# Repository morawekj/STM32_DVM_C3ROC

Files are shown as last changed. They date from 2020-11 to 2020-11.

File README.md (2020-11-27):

# STM32_DVM_C3ROC

This is a fork of the STM32 DVM V4 from Scott Zimmerman N3XCC / Repeater Builder
Inspired from a similar design: github.com/wojciechk8/MMDVM_pog
Low-pass filter design by SQ6POG

I design a new KiCad Design with some improvements and separate LED Board with I2C and RS232 Display connections. Also with an 5V 3.5A DC/DC converter with TI TPS54360(B) for the Raspberry PI, so that can powered from the radios DC voltage. Also add some ferrite beads and USBCL6 TVS protection. Connection to the LED/Display is a 20 Pin ribbon cable.

This project is mainly design for use for use on Chaos Computer Clubs Radio Teams (c3roc) DMR repeaters. All credits go to first designers. May be some others HAMs find this useful and feel free to use.

PCB and Components can be easy source by some prototype manufactures.

Enjoy RFguy DG3FDM

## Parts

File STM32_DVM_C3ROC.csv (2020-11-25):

ID | Designator | Footprint | Stückzahl | Comment | MFR.Part # | LCSC Part #
1 | R6,R51,R23 | Potentiometer_Bourns_3296W_Vertical | 3 | 100k | DNP
2 | X2 | DSUB-9_Female_Horizontal_P2.77x2.84mm_EdgePinOffset4.94mm_Housed_MountingHolesOffset7.48mm | 1 | To Radio | DNP
3 | SW1 | SW_Push_SPST_NO_Alps_SKRK | 1 | SW_Push | TS-1187A-C-C-B | C318889 | ext | 0,0348 $
4 | R32 | Potentiometer_Bourns_3296W_Vertical | 1 | 10k | DNP
5 | X1 | SMD-7050_4P | 1 | ASE-12MHz | O705012MHEA4SI | C70647 | ext | 0,4957 $
6 | U5 | TI_SO-PowerPAD-8_ThermalVias | 1 | TPS54360DDA | TPS54360DDAR | C44377 | ext | 0,9958 $
7 | U4,U3,U2 | SOT-23-6 | 3 | USBLC6-2SC6 | USBLC6-2SC6 | C7519 | ext | 0,0874 $
8 | U1 | LQFP-64_10x10mm_P0.5mm | 1 | STM32F446RETx | STM32F446RET6 | C69336 | ext | 3,5218 $
9 | TP7 | TestPoint_Pad_1.5x1.5mm | 1 | RSSI | DNP
10 | TP6 | TestPoint_Pad_1.5x1.5mm | 1 | TXA_R | DNP
11 | TP5,TP2,TP1 | TestPoint_Pad_1.5x1.5mm | 3 | TestPoint | DNP
12 | TP3 | TestPoint_Pad_1.5x1.5mm | 1 | RXA | DNP
13 | T4,T3,T2,T1 | SOT-23 | 4 | MMUN2214 | MMUN2214LT1G | C82089 | ext
14 | SJ1 | SolderJumper-2_P1.3mm_Open_Pad1.0x1.5mm | 1 | Jumper_2_Open | DNP
15 | R56,R50,R49,R48,R47,R46,R45,R44,R43,R42,R37 | R_0603_1608Metric | 11 | 560R | 0603WAF5600T5E | C23204 | basic | 0,0018 $
16 | R55,R53 | R_0603_1608Metric | 2 | 10k2 | 0603WAF1022T5E | C22772 | ext | 0,0024 $
17 | R54 | R_0603_1608Metric | 1 | 53k6 | 0603WAF5362T5E | C23074 | ext | 0,0026 $
18 | R52 | R_0603_1608Metric | 1 | 162k | 0603WAF1623T5E | C22815 | ext | 0,0026 $
19 | R41,R36,R34,R2,R1 | R_0603_1608Metric | 5 | 1k | 0603WAF1001T5E | C21190 | basic | 0,0021 $
20 | R35,R33,R19,R18,R8,R5,R17,R10,R4,R3 | R_0603_1608Metric | 10 | 10k | 0603WAF1002T5E | C25804 | basic | 0,0019 $
21 | R39 | R_0603_1608Metric | 1 | 4k7 | 0603WAF4701T5E | C23162 | basic | 0,0016 $
22 | R38,R30 | R_0603_1608Metric | 2 | 47k | 0603WAF4702T5E | C25819 | basic | 0,0018 $
23 | R31,R29,R9 | R_0603_1608Metric | 3 | 47R | 0603WAF470JT5E | C23182 | basic | 0,0024 $
24 | R28,R26 | R_0603_1608Metric | 2 | 3k9 | 0603WAF3901T5E | C23018 | basic | 0,0021 $
25 | R27,R24 | R_0603_1608Metric | 2 | 39k | 0603WAF3902T5E | C23153 | basic | 0,0019 $
26 | R25,R22 | R_0603_1608Metric | 2 | 3k3 | 0603WAF3301T5E | C22978 | basic | 0,0021 $
27 | R21,R16,R15 | R_0603_1608Metric | 3 | 100k | 0603WAF1003T5E | C25803 | basic | 0,0018 $
28 | R20 | R_0603_1608Metric | 1 | 68k | 0603WAF6802T5E | C23231 | basic | 0,0019 $
29 | R18 | R_0603_1608Metric | 4 | 523k | 0603WAF5233T5E | C23076 | ext | 0,0026 $
 | R40 | R_0603_1608Metric | 1 | 82k | 0603WAF8202T5E | C23254 | basic | 0,0021 $
30 | R14,R13,R12,R11 | R_0603_1608Metric | 4 | 22k | 0603WAF2202T5E | C31850 | basic | 0,0019 $
31 | R7 | R_0603_1608Metric | 1 | 100R | 0603WAF1000T5E | C22775 | basic | 0,0019 $
32 | Q1 | Crystal_SMD_3225-4Pin_3.2x2.5mm | 1 | Crystal_GND23 | 1C208000BC0R | C57131 | ext | 0,341 $
33 | LED12 | LED_0603_1608Metric | 1 | white |  | C2290 | basic | 0,0133 $
34 | LED11,LED10,LED9,LED8,LED7 | LED_0603_1608Metric | 5 | YEL | 19-213/Y2C-CQ2R2L/3T(CY) | C72038 | basic | 0,0233 $
35 | LED6,LED1 | LED_0603_1608Metric | 2 | RED | KT-0603R | C2286 | basic | 0,0079 $
36 | LED5 | LED_0603_1608Metric | 1 | GRN | 19-217/GHC-YR1S2/3T | C72043 | basic | 0,0375 $
37 | LED4,LED3 | LED_0603_1608Metric | 2 | ORG | E6C0603SEAC1UDA | C375450 | ext | 0,585 $
38 | LED2 | LED_0603_1608Metric | 1 | BLU | 19-217/BHC-ZL1M2RY/3T | C72041 | basic | 0,0242 $
39 | L1 | L_Coilcraft_XAL60xx_6.36x6.56mm | 1 | 8u2 | APS07A30M8R2 | C328254 | ext | 0,1502 $
40 | JP5 | PinHeader_2x10_P2.54mm_Vertical | 1 | To STM32 DVM | DNP
41 | JP4 | PinHeader_2x10_P2.54mm_Vertical | 1 | To LED + Display | DNP
42 | JP3 | PinHeader_2x03_P2.54mm_Vertical | 1 | Debug | DNP
43 | JP2 | PinHeader_1x04_P2.54mm_Vertical | 1 | Nextion Display | DNP
44 | JP1 | PinHeader_1x04_P2.54mm_Vertical | 1 | I2C Display | DNP
45 | J2 | USB_Micro-B_Molex_47346-0001 | 1 | USB_B_Micro | DNP
46 | IC4,IC3,IC2 | SO-8_3.9x4.9mm_P1.27mm | 3 | MCP6002 | MCP6002-I/SN | C116706 | ext | 0,2117 $
47 | FB23,FB22,FB21,FB20,FB19,FB18,FB17,FB16,FB15,FB14,FB13,FB12,FB11,FB10,FB9,FB8,FB7,FB6,FB5,FB4,FB3,FB2,FB1 | L_0603_1608Metric | 23 | 100 | GZ1608D601TF | C1002 | ext | 0,0068 $
48 | D2 | D_SMC | 1 | B560C | B560C-13-F | C85100 | ext | 0,1531 $
49 | D1 | SOT-23 | 1 | BAV70 | BAV70 | C68978 | basic | 0,027 $
50 | C43,C41 | C_1206_3216Metric | 2 | 1u | CL31B105KBHNNNE | C1848 | basic | 0,0324 $
51 | C42,C30,C27,C26,C24 | C_0603_1608Metric | 5 | 10n | 0603B103K500NT | C57112 | basic | 0,0055 $
52 | C38,C16,C10,C7,C6,C5,C3,C2,C1 | C_0603_1608Metric | 9 | 100n | CC0603KRX7R9BB104 | C14663 | basic | 0,0063 $
54 | C37 | C_0603_1608Metric | 1 | 47p | CL10C470JB8NNNC | C1671 | basic | 0,0072 $
55 | C36 | C_0603_1608Metric | 1 | 6n8 | 0603B682K500NT | C1631 | basic | 0,0021 $
56 | C35,C4,C32,C28,C18,C11,C9,C8 | C_1206_3216Metric | 8 | 4u7 | 1206B475K500NT | C29823 | basic | 0,0635 $
57 | C40,C39,C34,C33,C20,C19,C14 | C_1210_3225Metric | 7 | 22u | TMK325BJ226KM-P | C268020 | ext | 0,1356 $
58 | C31,C29 | C_0603_1608Metric | 2 | 680p | 0603B681K500NT | C1630 | basic | 0,0059 $
59 | C25,C23 | C_1206_3216Metric | 2 | 2u2 | CL31B225KBHNNNE | C50254 | basic | 0,0525 $
60 | C22,C21,C17,C15 | C_1210_3225Metric | 4 | 47u | GRM32ER61C476KE15L | C77101 | ext | 0,1884 $
61 | C13,C12 | C_0603_1608Metric | 2 | 10p | CL10C100JB8NNNC | C1634 | basic | 0,0083 $
62 | J1 | PinSocket_2x20_P2.54mm_Vertical | 1 | 40HAT | DNP
63 | H1,H2,H3,H4 | NPTH_3mm_ID | 4 | 3mm | DNP
64

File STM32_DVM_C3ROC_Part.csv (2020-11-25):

Designator | Footprint | Comment | LCSC | Part | #
R6,R51,R23 | Potentiometer_Bourns_3296W_Vertical | 100k
X2 | DSUB-9_Female_Horizontal_P2.77x2.84mm_EdgePinOffset4.94mm_Housed_MountingHolesOffset7.48mm | To | Radio
SW1 | SW_Push_SPST_NO_Alps_SKRK | SW_Push | C318889
R32 | Potentiometer_Bourns_3296W_Vertical | 10k
X1 | SMD-7050_4P | ASE-12MHz | C70647
U5 | TI_SO-PowerPAD-8_ThermalVias | TPS54360DDA | C44377
U4,U3,U2 | SOT-23-6 | USBLC6-2SC6 | C111212
U1 | LQFP-64_10x10mm_P0.5mm | STM32F446RETx | C69336
TP7 | TestPoint_Pad_1.5x1.5mm | RSSI
TP6 | TestPoint_Pad_1.5x1.5mm | TXA_R
TP5,TP2,TP1 | TestPoint_Pad_1.5x1.5mm | TestPoint
TP3 | TestPoint_Pad_1.5x1.5mm | RXA
T4,T3,T2,T1 | SOT-23 | MMUN2214 | C82089
SJ1 | SolderJumper-2_P1.3mm_Open_Pad1.0x1.5mm | Jumper_2_Open
R56,R50,R49,R48,R47,R46,R45,R44,R43,R42,R37 | R_0603_1608Metric | 560R | C23204
R55,R53 | R_0603_1608Metric | 10k2 | C22772
R54 | R_0603_1608Metric | 53k6 | C23074
R52 | R_0603_1608Metric | 162k | C22815
R41,R36,R34,R2,R1 | R_0603_1608Metric | 1k | C21190
R35,R33,R19,R8,R5,R17,R10,R4,R3 | R_0603_1608Metric | 10k | C25804
R39 | R_0603_1608Metric | 4k7 | C23162
R38,R30 | R_0603_1608Metric | 47k | C25819
R31,R29,R9 | R_0603_1608Metric | 47R | C23182
R28,R26 | R_0603_1608Metric | 3k9 | C23018
R27,R24 | R_0603_1608Metric | 39k | C23153
R25,R22 | R_0603_1608Metric | 3k3 | C22978
R21,R16,R15 | R_0603_1608Metric | 100k | C25803
R20 | R_0603_1608Metric | 68k | C23231
R18 | R_0603_1608Metric | 523k | C23076
R40 | R_0603_1608Metric | 82k | C23254
R14,R13,R12,R11 | R_0603_1608Metric | 22k | C31850
R7 | R_0603_1608Metric | 100R | C22775
Q1 | Crystal_SMD_3225-4Pin_3.2x2.5mm | Crystal_GND23 | C57131
LED12 | LED_0603_1608Metric | white | C2290
LED11,LED10,LED9,LED8,LED7 | LED_0603_1608Metric | YEL | C72038
LED6,LED1 | LED_0603_1608Metric | RED | C2286
LED5 | LED_0603_1608Metric | GRN | C72043
LED4,LED3 | LED_0603_1608Metric | ORG | C375450
LED2 | LED_0603_1608Metric | BLU | C72041
L1 | L_Coilcraft_XAL60xx_6.36x6.56mm | 8u2 | C328254
JP5 | PinHeader_2x10_P2.54mm_Vertical | To | STM32 | DVM
JP4 | PinHeader_2x10_P2.54mm_Vertical | To | LED | + | Display
JP3 | PinHeader_2x03_P2.54mm_Vertical | Debug
JP2 | PinHeader_1x04_P2.54mm_Vertical | Nextion | Display
JP1 | PinHeader_1x04_P2.54mm_Vertical | I2C | Display
J2 | USB_Micro-B_Molex_47346-0001 | USB_B_Micro
IC4,IC3,IC2 | SO-8_3.9x4.9mm_P1.27mm | MCP6002 | C116706
FB23,FB22,FB21,FB20,FB19,FB18,FB17,FB16,FB15,FB14,FB13,FB12,FB11,FB10,FB9,FB8,FB7,FB6,FB5,FB4,FB3,FB2,FB1 | L_0603_1608Metric | 100n | C1002
D2 | D_SMC | B560C | C85100
D1 | SOT-23 | BAV70 | C68978
C43,C41 | C_1206_3216Metric | 1u | C1848
C42,C30,C27,C26,C24 | C_0603_1608Metric | 10n | C57112
C38,C16,C10,C7,C6,C5,C3,C2,C1 | C_0603_1608Metric | 100n | C14663
C37 | C_0603_1608Metric | 47p | C1671
C36 | C_0603_1608Metric | 6n8 | C1631
C35,C4,C32,C28,C18,C11,C9,C8 | C_1206_3216Metric | 4u7 | C29823
C40,C39,C34,C33,C20,C19,C14 | C_1210_3225Metric | 22u | C268020
C31,C29 | C_0603_1608Metric | 680p | C1630
C25,C23 | C_1206_3216Metric | 2u2 | C50254
C22,C21,C17,C15 | C_1210_3225Metric | 47u | C77101
C13,C12 | C_0603_1608Metric | 10p | C1634
J1 | PinSocket_2x20_P2.54mm_Vertical | 40HAT
H1,H2,H3,H4 | NPTH_3mm_ID | 3mm

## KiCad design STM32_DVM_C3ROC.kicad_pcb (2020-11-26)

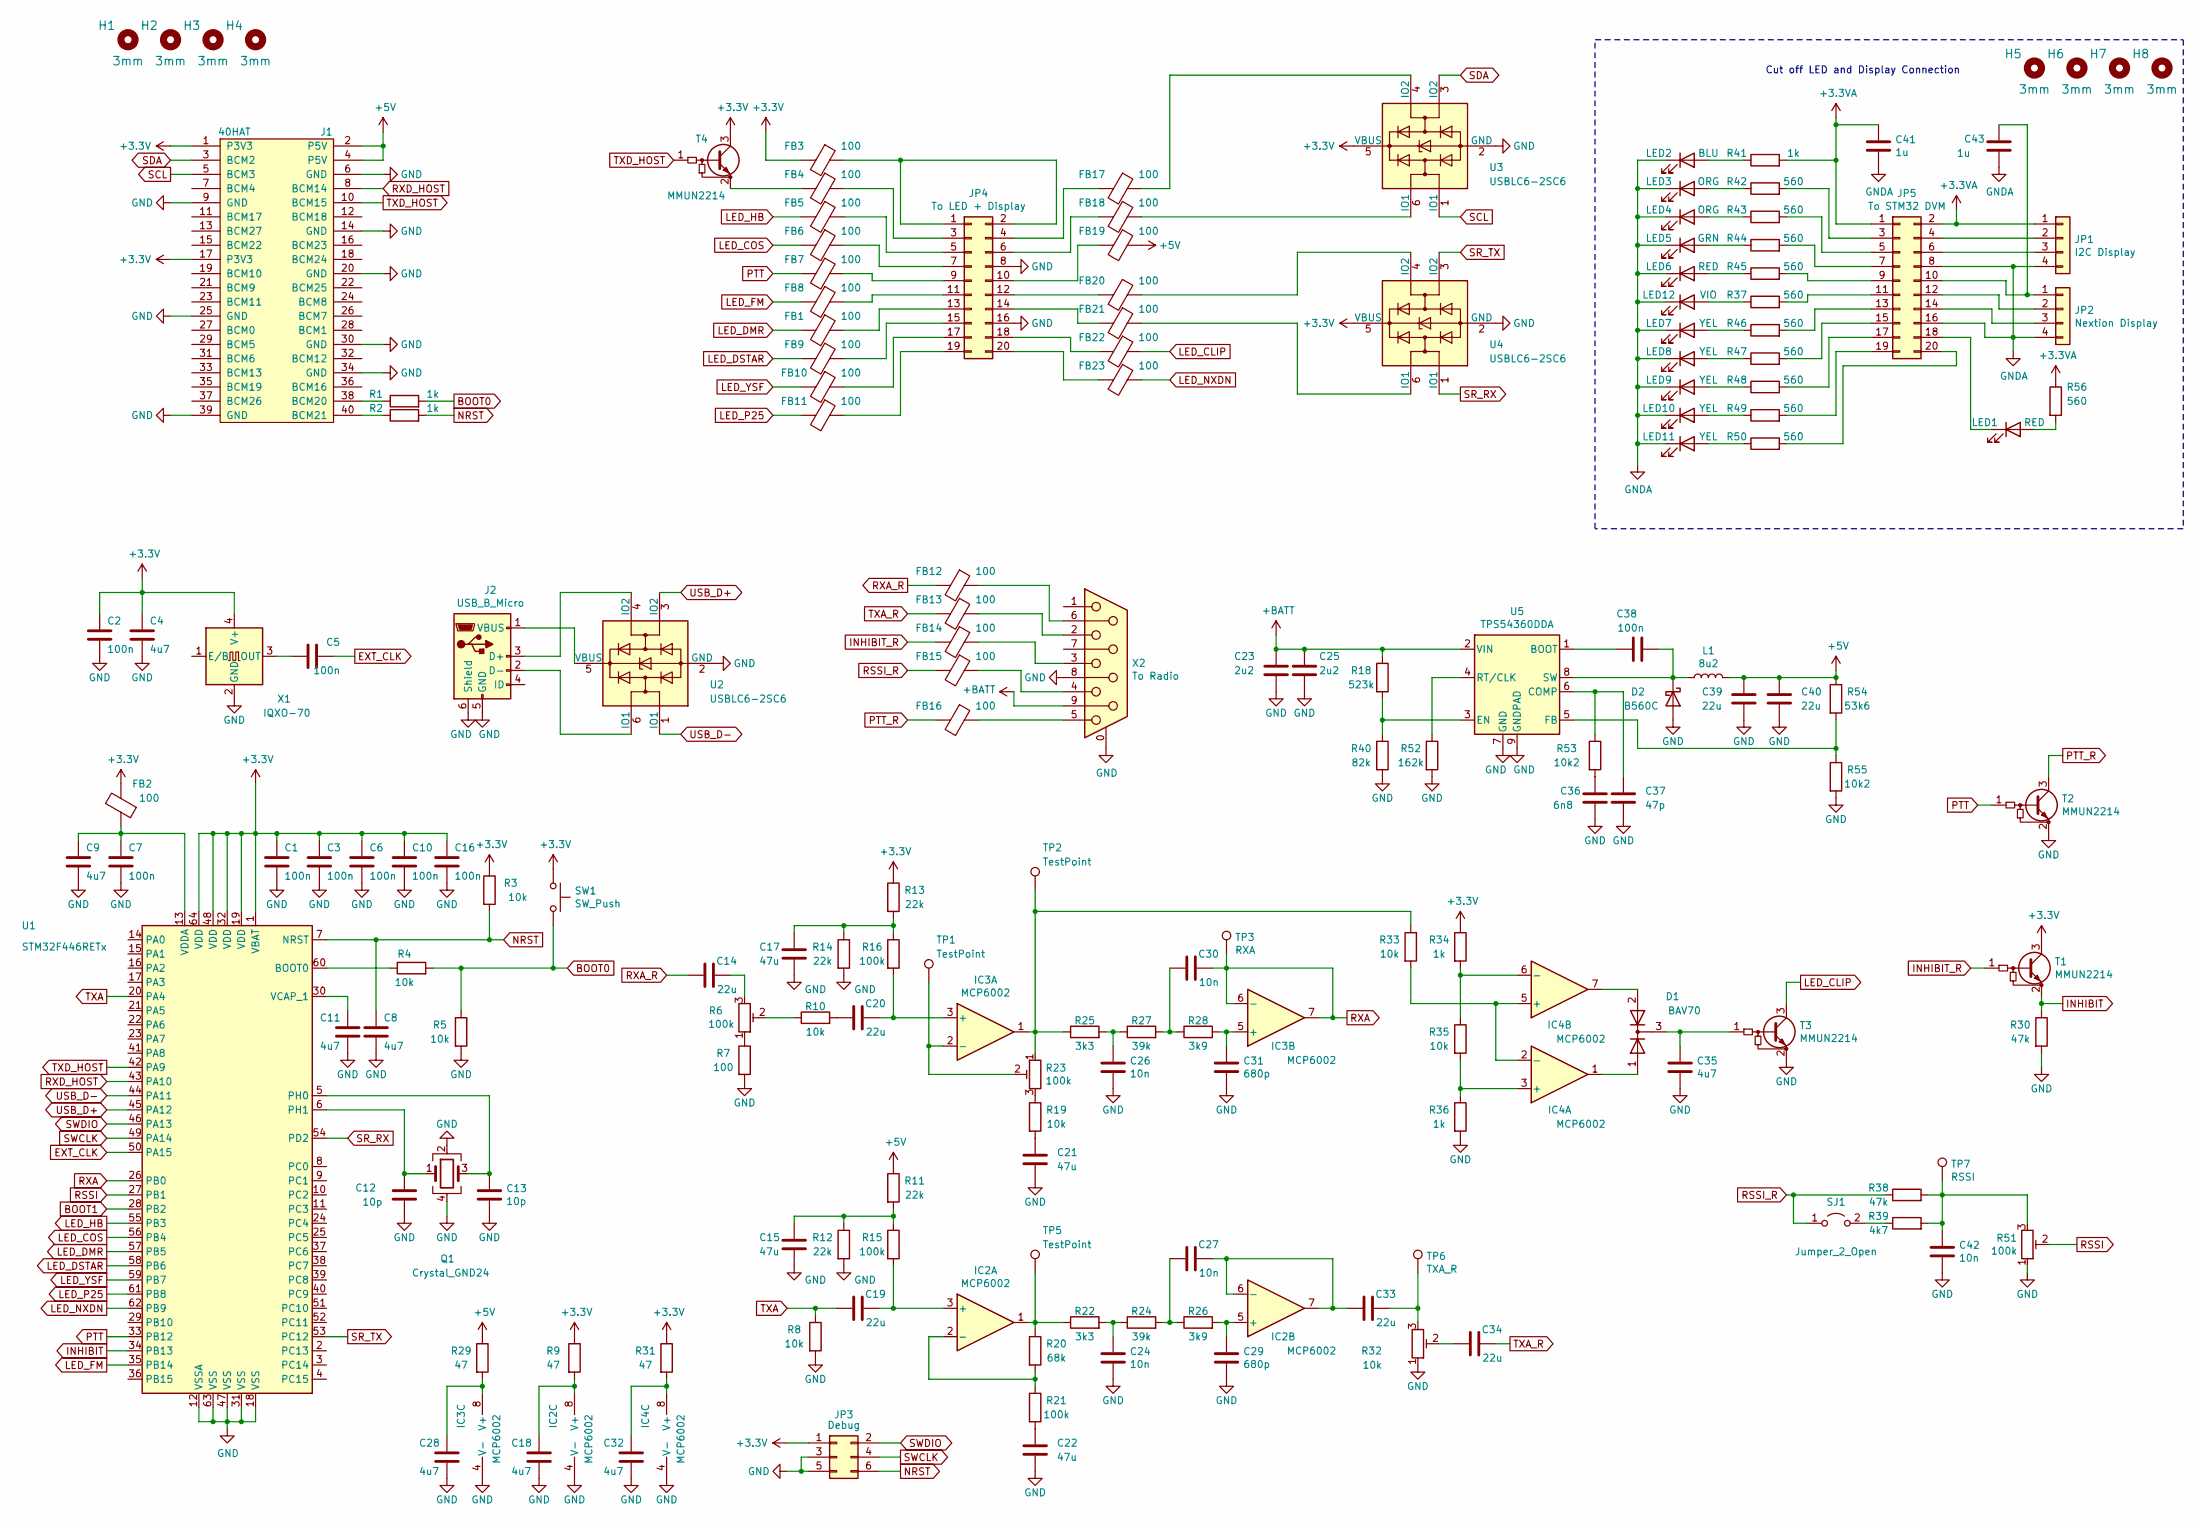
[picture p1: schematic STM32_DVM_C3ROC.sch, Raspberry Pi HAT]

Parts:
C1, C2, C3, C5, C6, C7, C10, C16, C38: 100n; C_0603_1608Metric
C4, C8, C9, C11, C18, C28, C32, C35: 4u7; C_1206_3216Metric
C12, C13: 10p; C_0603_1608Metric
C14, C19, C20, C33, C34, C39, C40: 22u; C_1210_3225Metric
C15, C17, C21, C22: 47u; C_1210_3225Metric
C23, C25: 2u2; C_1206_3216Metric
C24, C26, C27, C30, C42: 10n; C_0603_1608Metric
C29, C31: 680p; C_0603_1608Metric
C36: 6n8; C_0603_1608Metric
C37: 47p; C_0603_1608Metric
C41, C43: 1u; C_1206_3216Metric
D1: BAV70; SOT-23
D2: B560C; D_SMC
FB1, FB2, FB3, FB4, FB5, FB6, FB7, FB8, FB9, FB10, FB11, FB12, FB13, FB14, FB15, FB16, FB17, FB18, FB19, FB20, FB21, FB22, FB23: 100; L_0603_1608Metric
H1, H2, H3, H4, H5, H6, H7, H8: 3mm; NPTH_3mm_ID
IC2, IC3, IC4: MCP6002; SO-8_3.9x4.9mm_P1.27mm
J1: 40HAT; PinSocket_2x20_P2.54mm_Vertical
J2: USB_B_Micro; USB_Micro-B_Molex_47346-0001
JP1: I2C Display; PinHeader_1x04_P2.54mm_Vertical
JP2: Nextion Display; PinHeader_1x04_P2.54mm_Vertical
JP3: Debug; PinHeader_2x03_P2.54mm_Vertical
JP4: To LED + Display; PinHeader_2x10_P2.54mm_Vertical
JP5: To STM32 DVM; PinHeader_2x10_P2.54mm_Vertical
L1: 8u2; L_Bourns_SRP7028A_7.3x6.6mm
LED1, LED6: RED; LED_0603_1608Metric
LED2: BLU; LED_0603_1608Metric
LED3, LED4: ORG; LED_0603_1608Metric
LED5: GRN; LED_0603_1608Metric
LED7, LED8, LED9, LED10, LED11: YEL; LED_0603_1608Metric
LED12: VIO; LED_0603_1608Metric
Q1: Crystal_GND24; Crystal_SMD_3225-4Pin_3.2x2.5mm
R1, R2, R34, R36, R41: 1k; R_0603_1608Metric
R3, R4, R5, R8, R10, R19, R33, R35: 10k; R_0603_1608Metric
R6, R23, R51: 100k; Potentiometer_Bourns_3296W_Vertical
R7: 100; R_0603_1608Metric
R9, R29, R31: 47; R_0603_1608Metric
R11, R12, R13, R14: 22k; R_0603_1608Metric
R15, R16, R21: 100k; R_0603_1608Metric
R18: 523k; R_0603_1608Metric
R20: 68k; R_0603_1608Metric
R22, R25: 3k3; R_0603_1608Metric
R24, R27: 39k; R_0603_1608Metric
R26, R28: 3k9; R_0603_1608Metric
R30, R38: 47k; R_0603_1608Metric
R32: 10k; Potentiometer_Bourns_3296W_Vertical
R37, R42, R43, R44, R45, R46, R47, R48, R49, R50, R56: 560; R_0603_1608Metric
R39: 4k7; R_0603_1608Metric
R40: 82k; R_0603_1608Metric
R52: 162k; R_0603_1608Metric
R53, R55: 10k2; R_0603_1608Metric
R54: 53k6; R_0603_1608Metric
SJ1: Jumper_2_Open; SolderJumper-2_P1.3mm_Open_Pad1.0x1.5mm
SW1: SW_Push; SW_SPST_SKQG_WithoutStem
T1, T2, T3, T4: MMUN2214; SOT-23
TP1, TP2, TP5: TestPoint; TestPoint_Pad_D1.5mm
TP3: RXA; TestPoint_Pad_D1.5mm
TP6: TXA_R; TestPoint_Pad_D1.5mm
TP7: RSSI; TestPoint_Pad_D1.5mm
U1: STM32F446RETx; LQFP-64_10x10mm_P0.5mm
U2, U3, U4: USBLC6-2SC6; SOT-23-6
U5: TPS54360DDA; TI_SO-PowerPAD-8_ThermalVias
X1: IQXO-70; Oscillator_SMD_IQD_IQXO70-4Pin_7.5x5.0mm
X2: To Radio; DSUB-9_Female_Horizontal_P2.77x2.84mm_EdgePinOffset4.94mm_H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

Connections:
+3.3VA: C41.1, JP1.1, JP5.1, JP5.2, R41.2, R56.1
+3V3: C1.1, C2.1, C3.1, C4.1, C6.1, C10.1, C16.1, FB2.2, FB3.2, J1.1 (P3V3), J1.17 (P3V3), JP3.1, R3.1, R9.1, R13.1, R31.1, R34.1, SW1.1, T1.3 (C), T4.3 (C), U1.1 (VBAT), U1.19 (VDD), U1.32 (VDD), U1.48 (VDD), U1.64 (VDD), U3.5 (VBUS), U4.5 (VBUS), X1.4 (V+)
+5V: C39.1, C40.1, FB19.1, J1.2 (P5V), J1.4 (P5V), L1.2, R11.1, R29.1, R54.1
+BATT: C23.1, C25.1, R18.1, U5.2 (VIN), X2.9
BOOT0: R1.2, R4.2, R5.1, SW1.2
EXT_CLK: C5.2, U1.50 (PA15)
GND: C1.2, C2.2, C3.2, C4.2, C6.2, C7.2, C8.2, C9.2, C10.2, C11.2, C12.2, C13.2, C15.2, C16.2, C17.2, C18.2, C21.2, C22.2, C23.2, C24.2, C25.2, C26.2, C28.2, C29.2, C31.2, C32.2, C35.2, C36.2, C37.2, C39.2, C40.2, C42.2, D2.2 (A), IC2.4 (V-), IC3.4 (V-), IC4.4 (V-), J1.6 (GND), J1.9 (GND), J1.14 (GND), J1.20 (GND), J1.25 (GND), J1.30 (GND), J1.34 (GND), J1.39 (GND), J2.5 (GND), J2.6 (Shield), JP3.3, JP3.5, JP4.8, JP4.16, Q1.2, Q1.4, R5.2, R7.2, R8.2, R12.2, R14.2, R30.2, R32.1, R36.2, R40.2, R51.1, R52.2, R55.2, T2.2 (E), T3.2 (E), U1.12 (VSSA), U1.18 (VSS), U1.31 (VSS), U1.47 (VSS), U1.63 (VSS), U2.2 (GND), U3.2 (GND), U4.2 (GND), U5.7 (GND), U5.9 (GNDPAD), X1.2 (GND), X2.0 (PAD), X2.8
GNDA: C41.2, C43.2, JP1.4, JP2.4, JP5.8, JP5.16, LED2.1 (K), LED3.1 (K), LED4.1 (K), LED5.1 (K), LED6.1 (K), LED7.1 (K), LED8.1 (K), LED9.1 (K), LED10.1 (K), LED11.1 (K), LED12.1 (K)
INHIBIT: R30.1, T1.2 (E), U1.34 (PB13)
INHIBIT_R: FB14.2, T1.1 (B)
LED_CLIP: FB22.1, T3.3 (C)
LED_COS: FB6.2, U1.56 (PB4)
LED_DMR: FB1.2, U1.57 (PB5)
LED_DSTAR: FB9.2, U1.58 (PB6)
LED_FM: FB8.2, U1.35 (PB14)
LED_HB: FB5.2, U1.55 (PB3)
LED_NXDN: FB23.1, U1.62 (PB9)
LED_P25: FB11.2, U1.61 (PB8)
LED_YSF: FB10.2, U1.59 (PB7)
NRST: C8.1, JP3.6, R2.2, R3.2, U1.7 (NRST)
unnamed: C5.1, X1.3 (OUT)
unnamed: C7.1, C9.1, FB2.1, U1.13 (VDDA)
unnamed: C11.1, U1.30 (VCAP_1)
unnamed: C12.1, Q1.1, U1.6 (PH1)
unnamed: C13.1, Q1.3, U1.5 (PH0)
unnamed: C14.2, R6.3
unnamed: C15.1, R11.2, R12.1, R15.1
unnamed: C17.1, R13.2, R14.1, R16.1
unnamed: C18.1, IC2.8 (V+), R9.2
unnamed: C19.2, IC2.3 (+), R15.2
unnamed: C20.1, R10.2
unnamed: C20.2, IC3.3 (+), R16.2
unnamed: C21.1, R19.2
unnamed: C22.1, R21.2
unnamed: C24.1, R22.2, R24.1
unnamed: C26.1, R25.2, R27.1
unnamed: C27.1, R24.2, R26.1
unnamed: C27.2, C33.1, IC2.6 (-), IC2.7
unnamed: C28.1, IC3.8 (V+), R29.2
unnamed: C29.1, IC2.5 (+), R26.2
unnamed: C30.1, R27.2, R28.1
unnamed: C31.1, IC3.5 (+), R28.2
unnamed: C32.1, IC4.8 (V+), R31.2
unnamed: C33.2, R32.3, TP6.1
unnamed: C34.1, R32.2
unnamed: C35.1, D1.3 (K), T3.1 (B)
unnamed: C36.1, R53.2
unnamed: C37.1, R53.1, U5.6 (COMP)
unnamed: C38.1, U5.1 (BOOT)
unnamed: C38.2, D2.1 (K), L1.1, U5.8 (SW)
unnamed: C42.1, R38.2, R39.2, R51.3, TP7.1
unnamed: C43.1, JP2.1, JP5.10
unnamed: D1.1 (A), IC4.1
unnamed: D1.2 (A), IC4.7
unnamed: FB1.1, JP4.13
unnamed: FB3.1, JP4.1, JP4.2
unnamed: FB4.1, JP4.3
unnamed: FB4.2, T4.2 (E)
unnamed: FB5.1, JP4.5
unnamed: FB6.1, JP4.7
unnamed: FB7.1, JP4.9
unnamed: FB8.1, JP4.11
unnamed: FB9.1, JP4.15
unnamed: FB10.1, JP4.17
unnamed: FB11.1, JP4.19
unnamed: FB12.1, X2.6
unnamed: FB13.1, X2.2
unnamed: FB14.1, X2.3
unnamed: FB15.1, X2.4
unnamed: FB16.1, X2.5
unnamed: FB17.1, U3.4 (IO2)
unnamed: FB17.2, JP4.4
unnamed: FB18.1, U3.6 (IO1)
unnamed: FB18.2, JP4.6
unnamed: FB19.2, JP4.10
unnamed: FB20.1, U4.4 (IO2)
unnamed: FB20.2, JP4.12
unnamed: FB21.1, U4.6 (IO1)
unnamed: FB21.2, JP4.14
unnamed: FB22.2, JP4.18
unnamed: FB23.2, JP4.20
unnamed: IC2.1, R20.1, R22.1, TP5.1
unnamed: IC2.2 (-), R20.2, R21.1
unnamed: IC3.1, R23.1, R25.1, R33.1, TP2.1
unnamed: IC3.2 (-), R23.2, TP1.1
unnamed: IC4.2 (-), IC4.5 (+), R33.2
unnamed: IC4.3 (+), R35.2, R36.1
unnamed: IC4.6 (-), R34.2, R35.1
unnamed: J1.38 (BCM20), R1.1
unnamed: J1.40 (BCM21), R2.1
unnamed: J2.1 (VBUS), U2.5 (VBUS)
unnamed: J2.2 (D-), U2.6 (IO1)
unnamed: J2.3 (D+), U2.4 (IO2)
unnamed: JP1.2, JP5.4
unnamed: JP1.3, JP5.6
unnamed: JP2.2, JP5.12
unnamed: JP2.3, JP5.14
unnamed: JP5.3, R42.2
unnamed: JP5.5, R43.2
unnamed: JP5.7, R44.2
unnamed: JP5.9, R45.2
unnamed: JP5.11, R37.2
unnamed: JP5.13, R46.2
unnamed: JP5.15, R47.2
unnamed: JP5.17, R48.2
unnamed: JP5.18, LED1.1 (K)
unnamed: JP5.19, R49.2
unnamed: JP5.20, R50.2
unnamed: LED1.2 (A), R56.2
unnamed: LED2.2 (A), R41.1
unnamed: LED3.2 (A), R42.1
unnamed: LED4.2 (A), R43.1
unnamed: LED5.2 (A), R44.1
unnamed: LED6.2 (A), R45.1
unnamed: LED7.2 (A), R46.1
unnamed: LED8.2 (A), R47.1
unnamed: LED9.2 (A), R48.1
unnamed: LED10.2 (A), R49.1
unnamed: LED11.2 (A), R50.1
unnamed: LED12.2 (A), R37.1
unnamed: R4.1, U1.60 (BOOT0)
unnamed: R6.1, R7.1
unnamed: R6.2, R10.1
unnamed: R18.2, R40.1, U5.3 (EN)
unnamed: R19.1, R23.3
unnamed: R39.1, SJ1.2 (B)
unnamed: R52.1, U5.4 (RT/CLK)
unnamed: R54.2, R55.1, U5.5 (FB)
PTT: FB7.2, T2.1 (B), U1.33 (PB12)
PTT_R: FB16.2, T2.3 (C)
RSSI: R51.2, U1.27 (PB1)
RSSI_R: FB15.2, R38.1, SJ1.1 (A)
RXA: C30.2, IC3.6 (-), IC3.7, TP3.1, U1.26 (PB0)
RXA_R: C14.1, FB12.2
RXD_HOST: J1.8 (BCM14), U1.43 (PA10)
SCL: J1.5 (BCM3), U3.1 (IO1)
SDA: J1.3 (BCM2), U3.3 (IO2)
SR_RX: U1.54 (PD2), U4.1 (IO1)
SR_TX: U1.53 (PC12), U4.3 (IO2)
SWCLK: JP3.4, U1.49 (PA14)
SWDIO: JP3.2, U1.46 (PA13)
TXA: C19.1, R8.1, U1.20 (PA4)
TXA_R: C34.2, FB13.2
TXD_HOST: J1.10 (BCM15), T4.1 (B), U1.42 (PA9)
USB_D+: U1.45 (PA12), U2.3 (IO2)
USB_D-: U1.44 (PA11), U2.1 (IO1)

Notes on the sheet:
Cut off LED and Display Connection

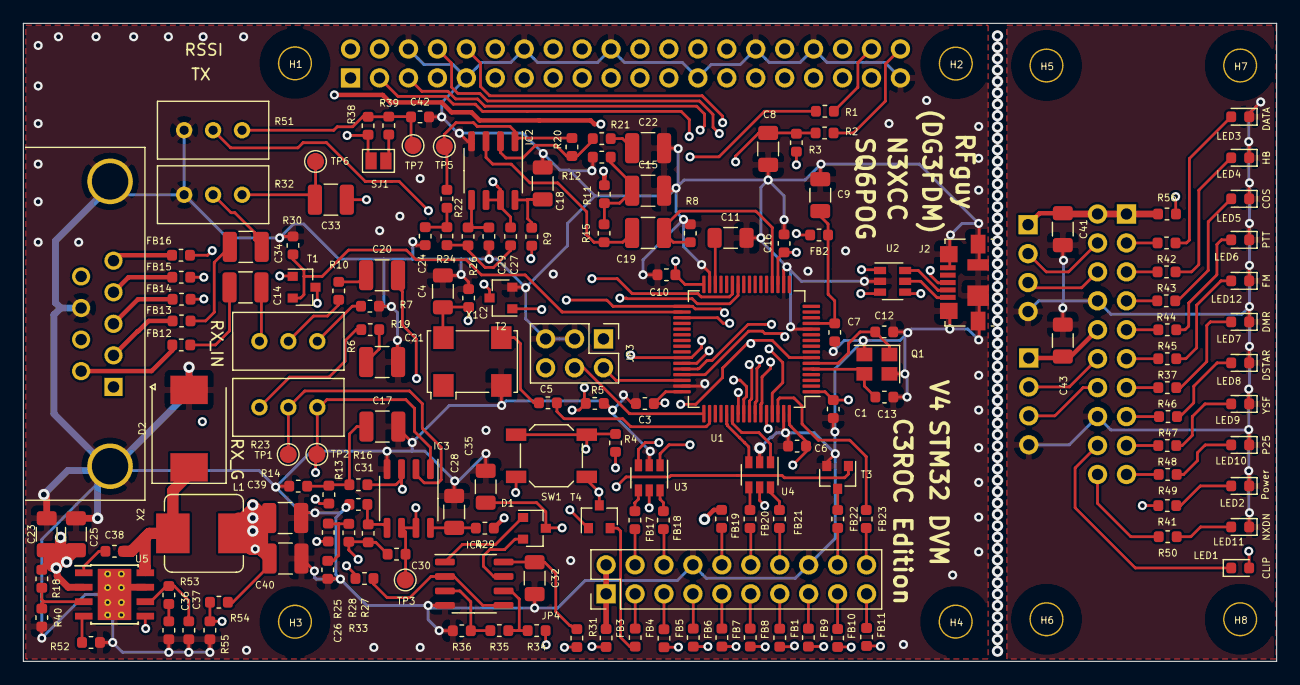
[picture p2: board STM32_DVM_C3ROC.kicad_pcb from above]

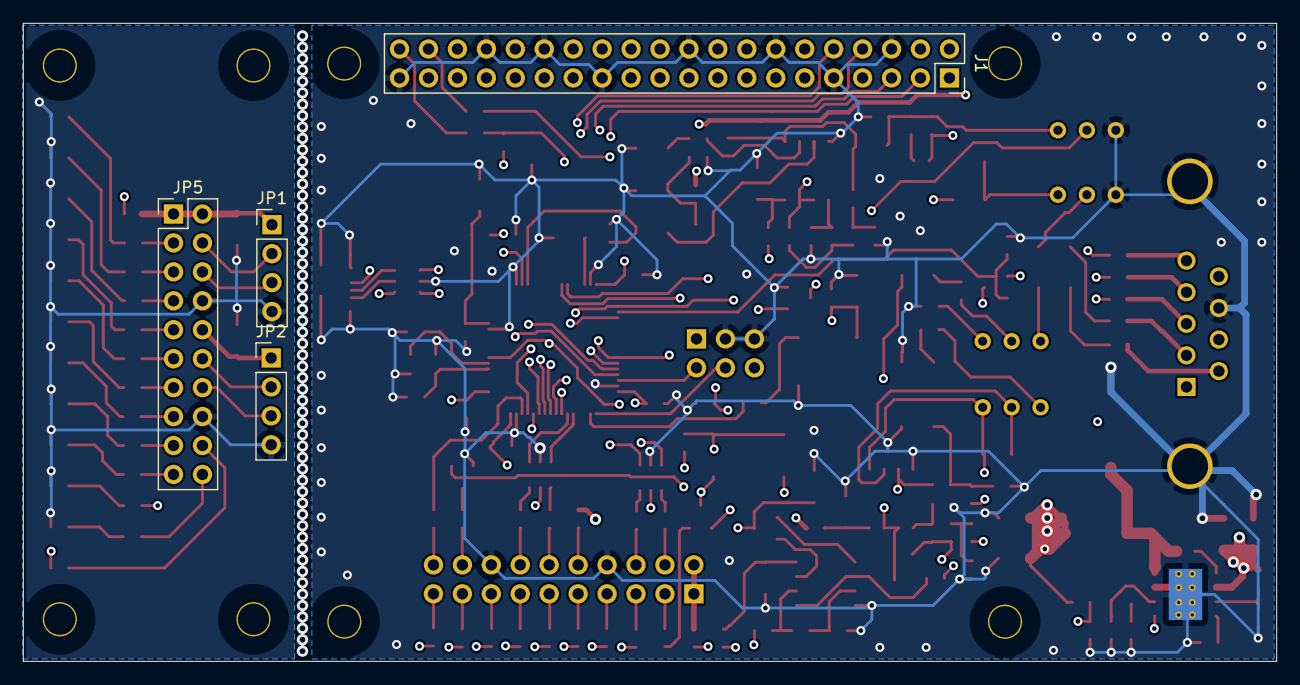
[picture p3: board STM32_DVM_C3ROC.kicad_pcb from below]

Board: 4 copper layers, 110.0 x 56.0 mm, 174 parts (4 on the bottom side), 146 nets.

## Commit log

2020-11-17 KiCad Project mit Pi Hat Template angelegt
    [STM32_DVM_C3ROC.kicad_pcb, STM32_DVM_C3ROC.sch]
2020-11-18 Schaltplan bis auf USB und DC/DC komplett
    [STM32_DVM_C3ROC.sch]
2020-11-18 Schaltplan fertig, Footprints zugewiesen, PCB Beginn platzierung
    [STM32_DVM_C3ROC.kicad_pcb, STM32_DVM_C3ROC.sch]
2020-11-18 Zwei Fehler im Schaltplan gefixt
    [STM32_DVM_C3ROC.sch]
2020-11-19 Etwas Bauteil Schubsen
    [STM32_DVM_C3ROC.sch]
2020-11-19 Platzierung 90 % komplett
    [STM32_DVM_C3ROC.kicad_pcb, STM32_DVM_C3ROC.sch]
2020-11-19 LCSC Part List angelegt, Footprints angepasst
    [STM32_DVM_C3ROC.csv, STM32_DVM_C3ROC.kicad_pcb, STM32_DVM_C3ROC.sch]
2020-11-22 Layout 80 %, kleine Korrekturen
    [STM32_DVM_C3ROC.csv, STM32_DVM_C3ROC.kicad_pcb, STM32_DVM_C3ROC.sch]
2020-11-23 Layout fertig für review
    [STM32_DVM_C3ROC.kicad_pcb, STM32_DVM_C3ROC.sch]
2020-11-25 Layout fertig, Produktionsdaten für JCLPCB erzeugt
    [STM32_DVM_C3ROC.csv, STM32_DVM_C3ROC.kicad_pcb, STM32_DVM_C3ROC.sch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]
2020-11-26 Produktionsdaten für JCLPCB korrigiert
    [STM32_DVM_C3ROC.kicad_pcb]
